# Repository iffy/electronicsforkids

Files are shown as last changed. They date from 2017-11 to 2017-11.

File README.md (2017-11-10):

The directories above contain some fun electronics projects for kids (or anyone that wants to do some electronic stuff).

# How to get stuff

- I've ordered PCBs from [oshpark.com](https://oshpark.com/).
- I've ordered parts (everything that goes on the board) from [Mouser](https://www.mouser.com/)
- Projects include a `bom.txt` file which you can upload to Mouser when ordering parts.
- If you need a soldering iron, this one looks like a really good deal: [https://amzn.com/B06XZ31W3M](https://amzn.com/B06XZ31W3M)

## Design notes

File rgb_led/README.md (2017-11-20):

This circuit board has three knobs (pots) and one red, green, blue LED.  Turning the knobs adjusts the amount of red/green/blue emitted.

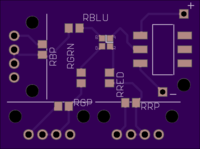
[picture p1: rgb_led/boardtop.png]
Board

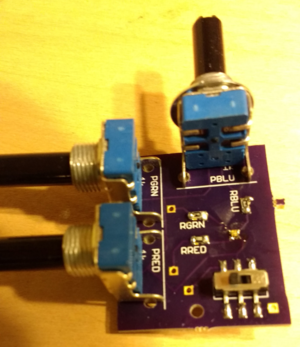
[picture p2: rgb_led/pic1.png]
Board with LED on

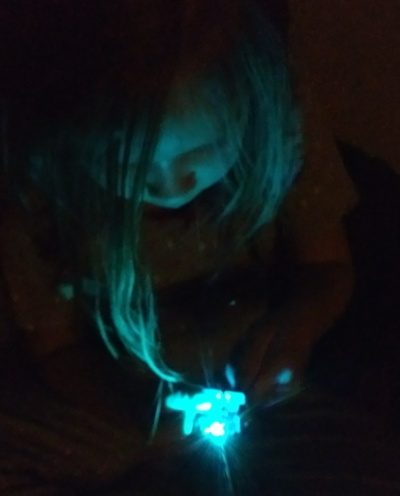
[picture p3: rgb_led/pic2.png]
Bluish-green light


# How to orient the LED

The anode of the LED attaches to the top-right pad.  There ought to be two white lines around the anode pad.  When looking at the LED, look for a little L shape inside--that's the red corner which goes to the bottom right.

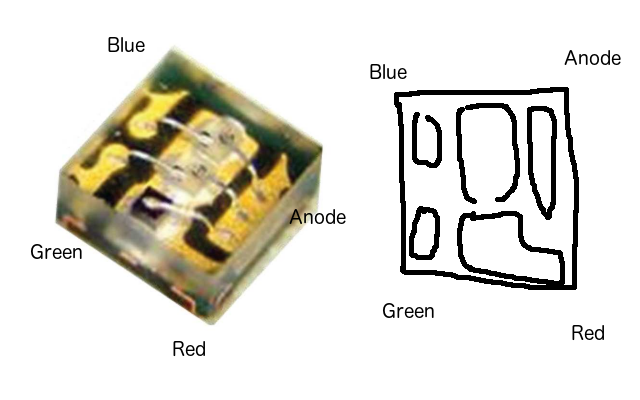
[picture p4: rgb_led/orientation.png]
Orienting the LED


The white arrow here is pointing to the anode pad:

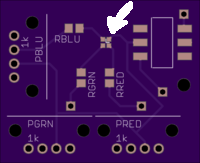
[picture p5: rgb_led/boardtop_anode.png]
Anode


# How to solder the tiny LED

It's pretty tricky to solder the LED, but it can be done.  Put a little solder on *one* pad.  Next hold the LED in place on the solder then place the iron on the pad to melt the solder and let the LED sink into place.  Pull the iron away and then let go of the LED.  The other 3 pads should be easier :)

# Which resistor goes where?

There are 3 required resistors.  Here are their values:

| Name | Value |
|---|---|
| RRED | 100 Ohm |
| RGRN | 60 Ohm |
| RBLU | 60 Ohm |

There are 3 optional resistors that, if present, will remove a lot of the "dead space" when turning the knobs.

| Name | Value |
|---|---|
| RRP | ~453 Ohm |
| RGP | ~422 Ohm |
| RBP | 300 Ohm |

# Battery

This takes a single CR2032 battery.

# Improvements

Things I'd like to do if I redesign it:

- Find physically smaller pots.  They're disproportionally huge.
- Use a button instead of a switch (so they don't die).

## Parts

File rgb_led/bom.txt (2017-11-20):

PTV111-1420A-B102 3
LRTBR48G-P9Q7-1+R7S5-26+N5P-68-ZB 1
BAT-HLD-001 1
ERJ-6ENF56R0V 2
RC0805FR-07100RL 1
JS202011SCQN 1
ERJ-6ENF3000V 1
ERJ-6ENF4220V 1
ERJ-6ENF4530V 1

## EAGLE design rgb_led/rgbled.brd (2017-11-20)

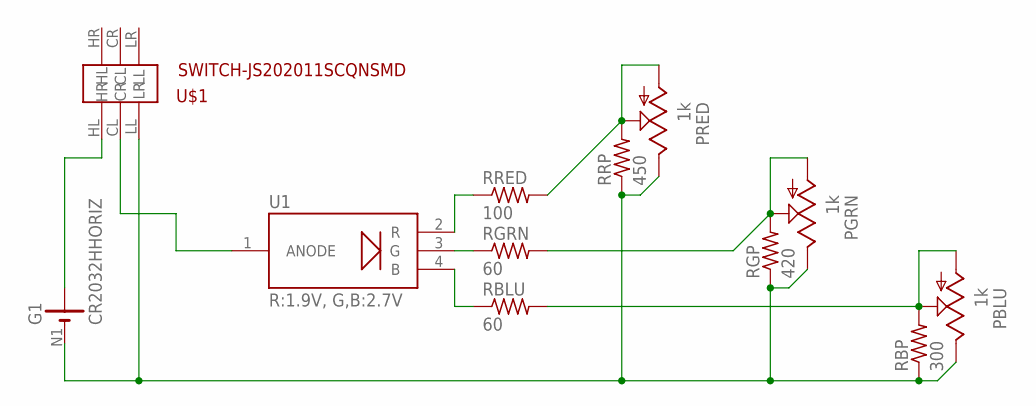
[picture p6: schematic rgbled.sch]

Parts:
G1: CR2032HHORIZ; LINX-BAT-HLD-001
PBLU: 1k; PTV111-1
PGRN: 1k; PTV111-1
PRED: 1k; PTV111-1
RBLU: 60; M0805
RBP: 300; R0805
RGP: 420; R0805
RGRN: 60; M0805
RRED: 100; M0805
RRP: 450; R0805
U1: R:1.9V, G,B:2.7V; LRTB_R48G
U$1: SWITCH-JS202011SCQNSMD; SWITCH-JS202011CQN

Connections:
unnamed: U1.1 (ANODE), U$1.CL
unnamed: RRED.1, U1.2 (R)
unnamed: RGRN.1, U1.3 (G)
unnamed: RBLU.1, U1.4 (B)
unnamed: PGRN.2 (S), PGRN.3 (A), RGP.2, RGRN.2
unnamed: PBLU.2 (S), PBLU.3 (A), RBLU.2, RBP.2
unnamed: G1.P@1 (+), G1.P@2 (+), U$1.HL
unnamed: G1.N1 (-), PBLU.1 (E), PGRN.1 (E), PRED.1 (E), RBP.1, RGP.1, RRP.1, U$1.LL
RRP: PRED.2 (S), PRED.3 (A), RRED.2, RRP.2

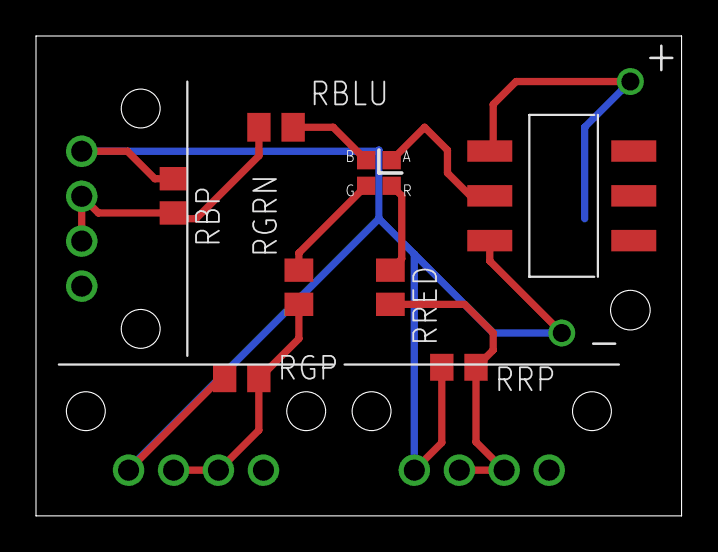
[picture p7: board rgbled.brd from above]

Board: 2 copper layers, 35.9 x 26.7 mm, 12 parts (1 on the bottom side), 9 nets.

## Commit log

2017-11-09 Add RGB LED project
    [rgbled.brd, rgbled.sch]
2017-11-20 New version of rgbled
    [rgbled.brd, rgbled.sch]
2017-11-20 Add battery
